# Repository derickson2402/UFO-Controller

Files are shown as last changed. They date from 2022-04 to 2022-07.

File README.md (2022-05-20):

# UFO-Controller

This summer, several of us wanted to build some quadcopter drones (what can I say, we're a house full of bored engineers :smiley:).
Eventually, we'd like to hook up FPV cameras, GPS units, and some other fun gizmos so that we can do cool stuff like FPV racing, autonomous path following with GPS, and smart object detection and wayfinding using computer vision.
Currently the project is in early stages, but I am documenting all the software as I go and when we have everything working I will make sure to include assembly instructions as well.

Much of the transmitter code is extended from [akarsh98](https://github.com/akarsh98) on GitHub and [this guide on PPM via Arduino](https://quadmeup.com/generate-ppm-signal-with-arduino/). Thanks akarsh and Pawel!

## Included Files

Some of the code used here is from projects from almost a decade ago, so I made sure to grab a copy of all the libraries and such that are used here.
Each folder contains some component of either testing/building the drone, and each comes with its own README and any dependencies.

Folder | Description
---|---|
```Arduino-ISP```     | Copied from Arduino IDE built-in example 11. Allows an Uno to program a Nano over ISP
```Wiring-Diagrams``` | PCB designs and board pinouts for transceiver, flight controller, etc for KiCad 6.0. Includes KiCad files for MPU breakout board.
```Hardware-Tests```  | Various programs for verifying that individual electronic components are working
```MultiWii```        | Flight control software from [MultiWii.com](http://www.multiwii.com/)
```MultiWii-GUI```    | Configuration GUI for ```MultiWii```
```Transceiver```     | Instructions for using pair of Arduino as radio transmitter to drone

## Testing/Verifying Hardware

In the ```Hardware-Tests``` folder are some basic programs for testing that various components are working.
There is another README in the folder which will walk you through everything.
I highly recommend you verify all of your hardware is working correctly BEFORE trying everything together, since there is nothing worse than spending hours on a "software" bug that doesn't actually exist.
Plus if you're like me you bought the cheapest stuff you could find and there's a good chance it won't all work right :smiley:.

## Configuring VS Code IDE

If you are like me, you really hate the default Arduino IDE and you would rather use VS Code.
To do this:

1. Install the Arduino VS Code extension
2. Choose AVR programmer and Arduino Nano board
3. In ```c_cpp_properties.json```, update ```compilerPath```, ```includePath```, and ```forcedInclude``` so your machine's section matches that of the Arduino (basically tell intellisense to use the Arduino's compiler)
4. Add ```USBCON``` to ```defines``` in ```c_cpp_properties.json```
5. If you need 3rd-party libraries, put them in ```src``` in the root of this repo and symlink ```src``` in your code root folder to it (Arduino compiler should recognize the ```src``` folder automatically)

## Resources

- https://create.arduino.cc/projecthub/akarsh98/diy-arduino-based-quadcopter-drone-948153
- https://www.hackster.io/robocircuits/arduino-quadcopter-e618c6
- https://howtomechatronics.com/projects/diy-arduino-rc-transmitter/
- https://www.modelflight.com.au/blog/a-guide-to-understanding-lipo-batteries
- https://www.instructables.com/DJi-F450-Quadcopter-How-to-Build-Home-Built/
- http://www.rctutor.org/the-parts-list.html
- [Read-only Amazon link for parts](https://www.amazon.com/hz/wishlist/ls/1BKLT1DHMK0VX?ref_=wl_share)
- [PPM communication via Arduino](https://quadmeup.com/generate-ppm-signal-with-arduino/)

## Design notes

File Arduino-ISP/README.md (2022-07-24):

# Arduino-ISP

This submodule is for using an Arduino Uno to program another Arduino via the ISP port.
This is useful for instance if the usb port is blocked on a device, but it is most useful if you need to burn a bootloader to a new board.

You can find the online instructions for the example built into the Arduino IDE on [Arduino's website](https://docs.arduino.cc/built-in-examples/arduino-isp/ArduinoISP).
Below is a transcript of the instructions.

## 1. Upload The ISP Sketch To The Programmer

Before wiring anything, upload the ```Arduino-ISP.ino``` sketch to your programmer board.
This file is the same as the one in the Arduino IDE examples.
Make sure to use the Port and Model of the programmer board for this step.

## 2. Connect The Programmer To The Target Board

See the diagram below that matches your use case. You should use an Uno board as the programmer, but you can program any kind of board.
For boards other than Nano or Uno, see the official instructions so you don't brick your board.

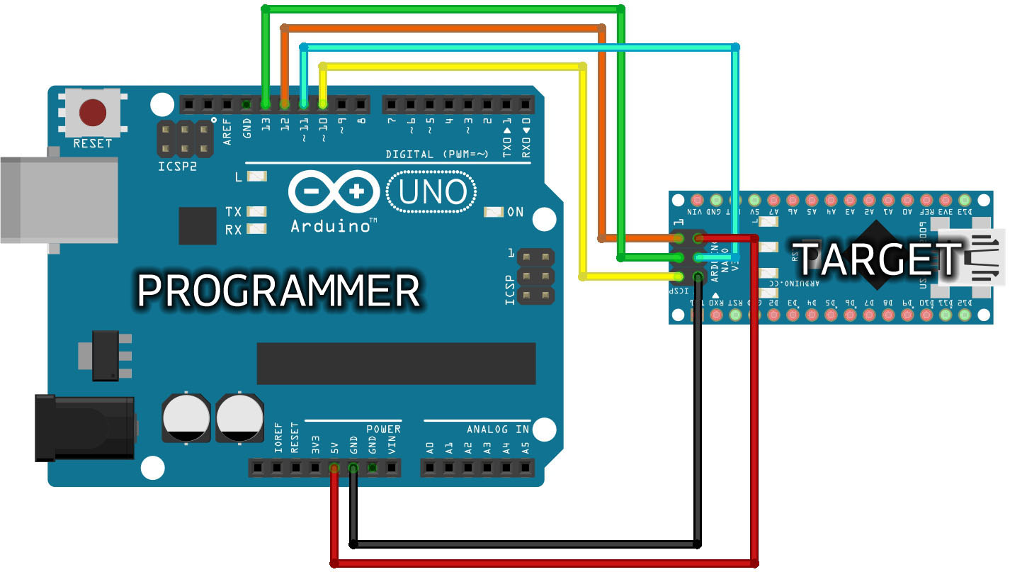
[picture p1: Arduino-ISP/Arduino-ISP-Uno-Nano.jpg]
Uno to Nano

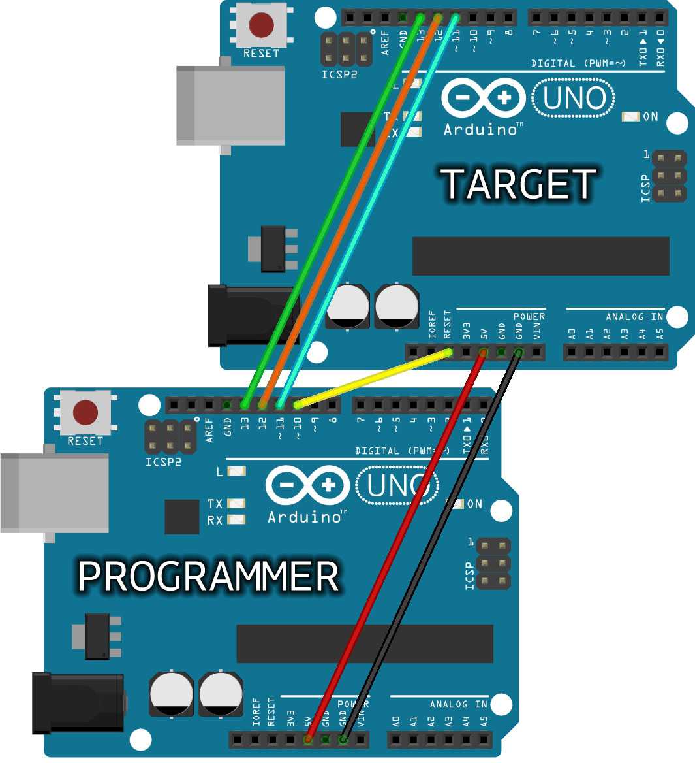
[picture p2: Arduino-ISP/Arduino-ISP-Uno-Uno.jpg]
Uno to Uno


## 3. Upload Code Or Bootloader

Once connected, you can upload to the target board as if it were connected directly to your computer.
Set the programmer to ```Arduino as ISP``` and the port and board type to the target board.
You can also choose ```Burn bootloader```, which may be necessary with new or mis-configured boards.

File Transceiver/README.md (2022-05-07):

# UFO Transceiver System

This submodule uses a pair of nRF24L01 transmitters, one as a transmitter one as a receiver. Check out the [RF24 GitHub](https://github.com/nRF24/RF24) for more help.
The PPM code is adapted from [this guide](https://quadmeup.com/generate-ppm-signal-with-arduino/) (thanks Pawel!).

## Wiring

See the corresponding images in ```Wiring-Diagrams``` for help wiring the modules.
It may be helpful to note that the chip needs a 3.3V power source but the logic pins are 5V tolerant, and therefore can be connected directly to the Arduino.
Also, to reduce noise, you might need a 10µF electrolytic or tantalum capacitor across the VCC and GND pins (this helps when using a poor power supply).
See the [COMMON_ISSUES.md](https://github.com/nRF24/RF24/blob/master/COMMON_ISSUES.md) file in the RF24 source repo for more help.

### Specific Configuration for Chips With External Antennas

nRF24L01+PA+LNA chips have a built in Power Amplifier and Low Noise Amplifier so they are very good for long range transmission.
With that said, they need an external 3.3V power source because said amplifier needs 3x as much current as the Arduino can give it.
Additionally, the chips may need electromagnetic shielding from the power supply.
Again see the [COMMON_ISSUES.md](https://github.com/nRF24/RF24/blob/master/COMMON_ISSUES.md) file in the RF24 source repo for more help.

## Deploying Code

When uploading the sketch to your Arduino's, there are some parameters at the top of ```Transceiver.ino``` you must configure.
There are short descriptions in the code but you can get more detail here:

1. Is the unit a receiver or a transmitter? Should debug mode be used?  
    a. Turning on debug mode deactivates PPM output (due to it needing timer interrupts)
2. Choose a unique 40 bit address for the Arduinos to talk on  
    a. Must be same for transmitter/receiver pair, and unique from other pairs
3. Choose a channel to use [0-125]  
    a. Must be same for transmitter/receiver pair, and unique from other pairs  
    b. Frequency band is 2,400MHz + (channel)MHz (so channel 81 = 2481MHz)  
    c. Higher channels sometimes interfere less with WiFi networks, may work better
4. You can re-define the CE and CSN pins in the code if you need (see nRF24 docs for more)
5. For the receiver only, choose PPM pin number and frame/pulse length  
    a. This must connect to the MultiWii controller pin 2  
    b. Communication is 12 channel PPM sum, where each channel is from [1000, 2000]µs (see [this guide](https://quadmeup.com/generate-ppm-signal-with-arduino/) for PPM help)  
    c. Channel order is set in MultiWii, default for this repo is in ```MultiWii/config.h``` as ```THROTTLE,YAW,PITCH,ROLL,AUX1,AUX2,AUX3,AUX4,8,9,10,11```  
    d. Frame length (total length of one transmission) is approximately ```(numChannels * 2000µsMaxSignalLength) + 3000µsFrameSpace```, and pulse length (signaling start of next channel) can be somewhere in [100, 500]µs

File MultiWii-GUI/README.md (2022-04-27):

# MultiWii Configuration GUI

This is a copy of the experimental GUI configuration program for MultiWii flight controllers.
You will need to install [Processing](https://processing.org/) on your computer, and then install the library ```controlp5``` by going into Processing under ```Sketch >> Import Library >> Add Library``` and searching for it (you can find help on their [GitHub](https://github.com/sojamo/controlp5) page).
When finished, you may need to restart Processing before launching ```MultiWiiConf.pde```.
See [MultiWii.com](http://www.multiwii.com/software) for help using the GUI.

---

Below is the original README from [multiwii/multiwii-gui-processing](https://github.com/multiwii/multiwii-gui-processing) on GitHub.

# multiwii-gui-processing for Processing 3.3 and later and ControlP5 2.2.5
# ***WORK IN PROGRESS***

Multiwii is a very common and respected flight controller, trully father of many version as CleanFligth, BetaFligth, iNAv and others.
But our beloved GUI was very outdated, this fork aims to fix that.

Currently working with:

Hardware: Arduino Mega, MPU6050, HMC5883L and BMP180.
Software: Processing 3.3 and ControlP5 release 2.2.5

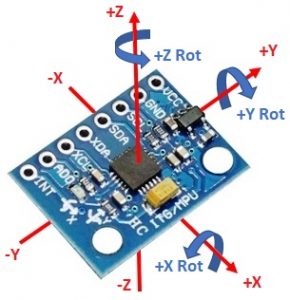
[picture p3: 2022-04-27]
Diagrams/Pinouts/MPU-6050-Orientation.jpg

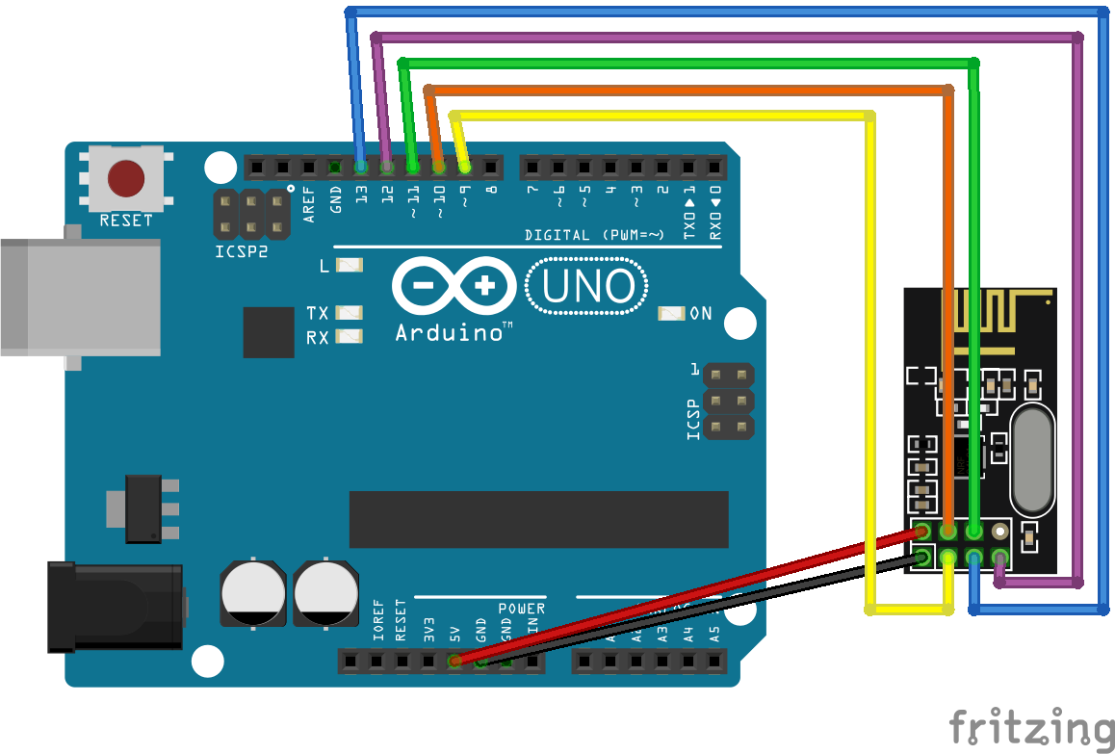
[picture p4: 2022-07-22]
Diagrams/Pinouts/UNO-nRF24L01.png

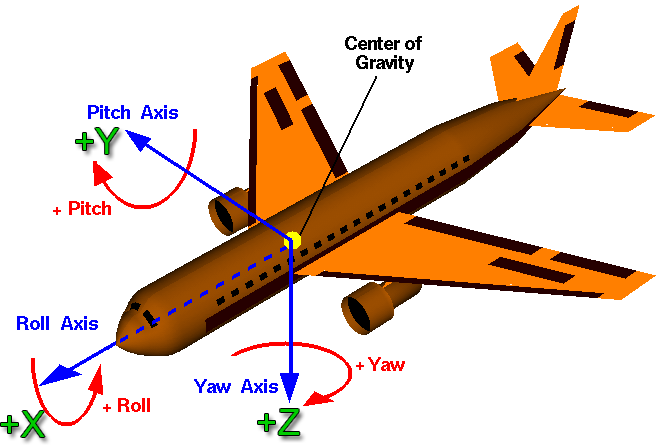
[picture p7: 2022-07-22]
Diagrams/NED Axes.png

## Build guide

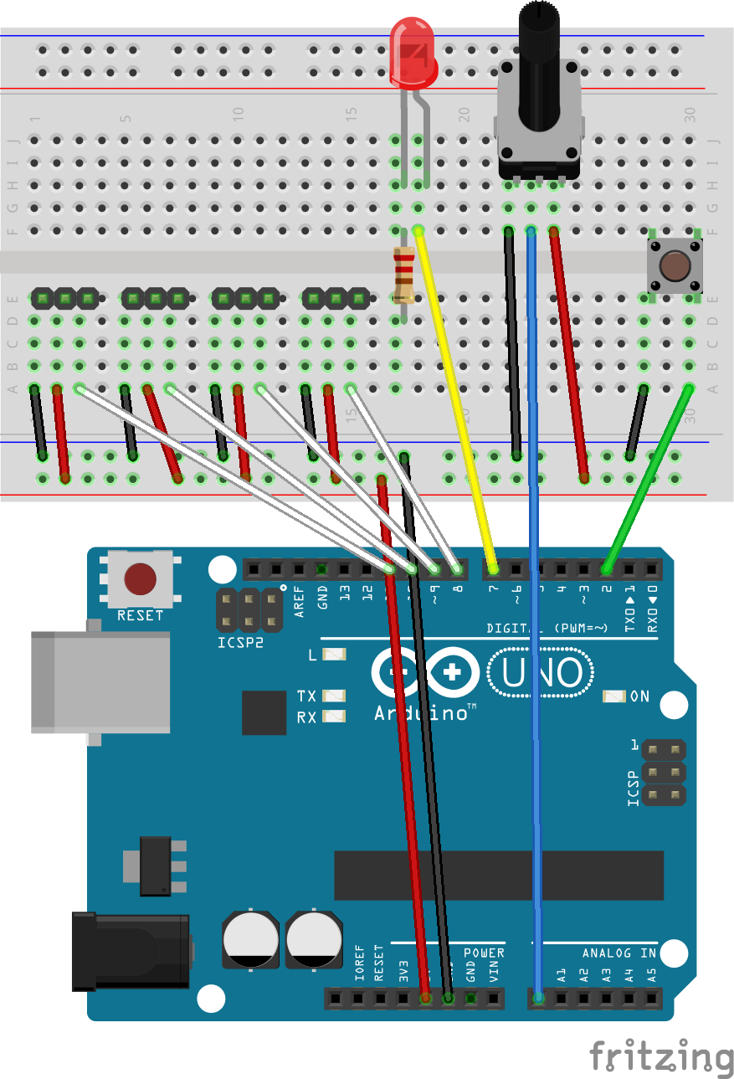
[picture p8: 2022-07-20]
Hardware-Tests/Motors/Motors Wiring Diagram.png

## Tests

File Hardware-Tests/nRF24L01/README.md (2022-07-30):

# Hardware-Tests/nRF24L01

The ```Transceiver``` program has a built-in debug mode which can be used for testing. Follow the instructions below to use this mode to verify that your transmitter and receiver are working correctly.

## 1. Test The Transmitter

Use the diagram in ```nRF24L01-TX-Test.png``` (embeded below) to create your transmitter.
Then deploy the Transceiver code with the ```DEBUG_MODE``` un-commented and the ```IS_RECEIVER``` commented.
This puts the board in transmitter debug mode.

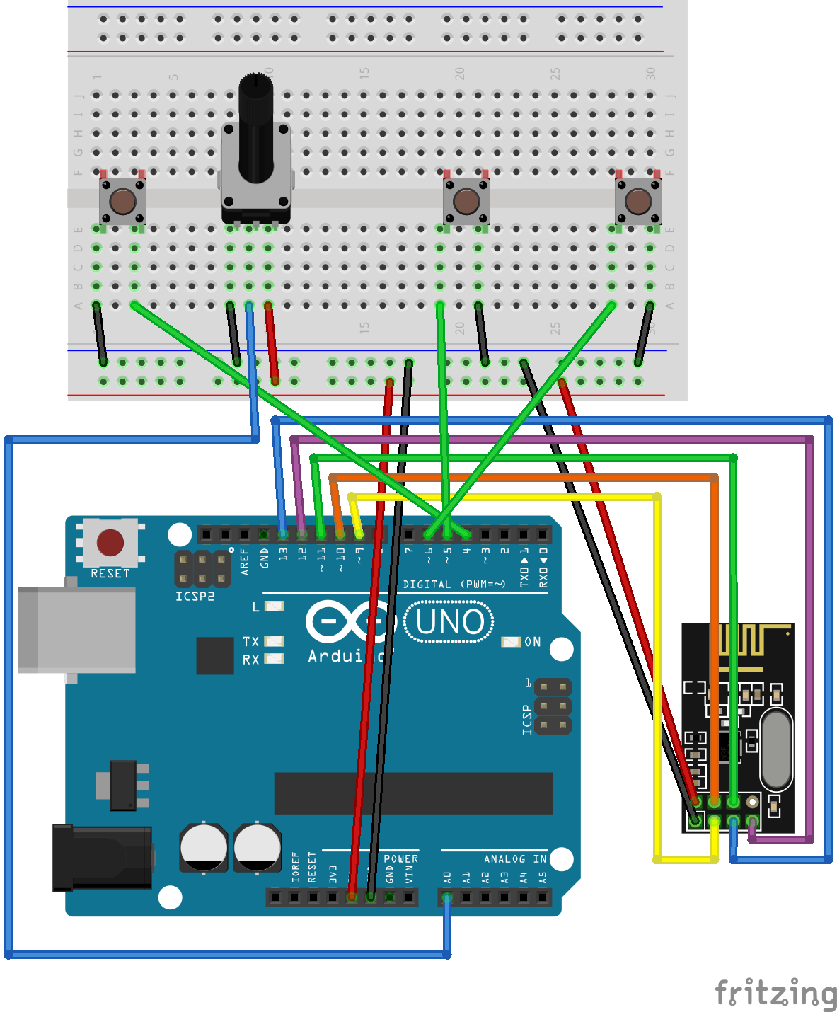
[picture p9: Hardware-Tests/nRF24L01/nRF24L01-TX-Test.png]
Wiring Diagram for testing transmission


You can connect via USB to verify that the data is being sent correctly.
Upon boot the radio will print its debug information.
Each second after that a copy of the data being transmitted is printed as ```throttle yaw pitch roll AUX1 AUX2```.
A working system should look like this after a few seconds:

```plaintext
SPI Frequency           = 10 Mhz
Channel                 = 120 (~ 2520 MHz)
Model                   = nRF24L01+
RF Data Rate            = 250 KBPS
RF Power Amplifier      = PA_MAX
RF Low Noise Amplifier  = Enabled
CRC Length              = 16 bits
Address Length          = 5 bytes
Static Payload Length   = 6 bytes
Auto Retry Delay        = 1500 microseconds
Auto Retry Attempts     = 15 maximum
Packets lost on
    current channel     = 0
Retry attempts made for
    last transmission   = 0
Multicast               = Disabled
Custom ACK Payload      = Disabled
Dynamic Payloads        = Disabled
Auto Acknowledgment     = Disabled
Primary Mode            = TX
TX address              = 0xe8e8f0f0e1
pipe 0 ( open ) bound   = 0xe8e8f0f0e1
pipe 1 (closed) bound   = 0xc2c2c2c2c2
pipe 2 (closed) bound   = 0xc3
pipe 3 (closed) bound   = 0xc4
pipe 4 (closed) bound   = 0xc5
pipe 5 (closed) bound   = 0xc6
0 127 127 127 0 0
0 127 127 127 0 0
0 127 127 127 0 0
78 152 102 127 0 0
78 152 102 127 0 0
78 152 102 127 0 0
78 127 127 127 0 0
```

## 2. Test the Receiver

Use the diagram in ```nRF24L01-RX-Test.png``` (embeded below) to create the receiver.
Deploy the Transceiver code with ```DEBUG_MODE``` and ```IS_RECEIVER``` un-commented.
This puts the board in receiver debug mode.

NOTE: See #12 in GitHub, there is some sort of hardware bug with using a Arduino Nano with the nRF24 chip.
Code is working correctly; if you do this setup with an UNO it will work.

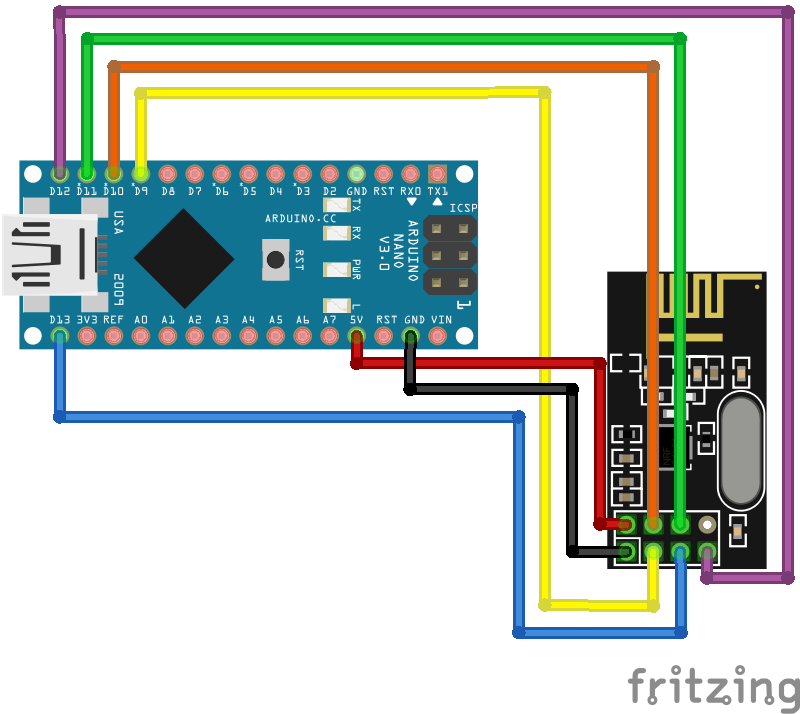
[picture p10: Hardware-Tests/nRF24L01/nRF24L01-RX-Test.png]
Wiring Diagram for testing receiving


Upload the transceiver code to the transmitter agin, but this time turn off debug mode.
Then plug the working transmitter into a wall outlet (not to your computer, as it is tedious to have multiple serial monitors open at once).
Connect the serial monitor to the receiver, and you should see the numbers from before on screen.
The radio information should also print, but it will be the receiver radio not the transmitter.
You should get something like this:

```plaintext
SPI Frequency           = 10 Mhz
Channel                 = 120 (~ 2476 MHz)
Model                   = nRF24L01+
RF Data Rate            = 250 KBPS
RF Power Amplifier      = PA_MAX
RF Low Noise Amplifier  = Enabled
CRC Length              = 16 bits
Address Length          = 5 bytes
Static Payload Length   = 6 bytes
Auto Retry Delay        = 1500 microseconds
Auto Retry Attempts     = 15 maximum
Packets lost on
    current channel     = 0
Retry attempts made for
    last transmission   = 0
Multicast               = Disabled
Custom ACK Payload      = Disabled
Dynamic Payloads        = Disabled
Auto Acknowledgment     = Disabled
Primary Mode            = RX
TX address              = 0xe7e7e7e7e7
pipe 0 (closed) bound   = 0xe7e7e7e7e7
pipe 1 ( open ) bound   = 0xe8e8f0f0e1
pipe 2 (closed) bound   = 0xc3
pipe 3 (closed) bound   = 0xc4
pipe 4 (closed) bound   = 0xc5
pipe 5 (closed) bound   = 0xc6
```

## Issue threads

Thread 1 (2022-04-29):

Create motion joystick for driving

derickson2402, 2022-04-29:
Originally I thought you could just plug an Xbox controller into an Arduino over USB and use its values to transmit to the drone. Turns out, there's only like 3 models of Arduino that have a full USB implementation available (normal ones aren't fast/powerful enough) so this won't work without a computer as a middle-man.

Instead, there are like 10 extra IMU chips lying around, so hooking one up to the transmitter and using it for motion controls should work just fine. Might be annoying later on (especially if there is drift) but it will be highly configurable and (hopefully) straightforward.

derickson2402, 2022-05-20:
Hm so forgot that the chip does not perform integration for us, it only reports change in angle and acceleration. Will need to perform the integration manually to track the current position of the 'joystick' and then send the corresponding values...

derickson2402, 2022-05-20:
Hmmm am I going to just have to write my own code to callibrate and track the sensor? This might be more difficult than just using an xbox controller :(

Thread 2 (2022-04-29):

Test transmitter/receiver pair

derickson2402, 2022-04-29:
The transmission code is already mostly implemented, but I haven't actually confirmed whether or not it works. See #1 as well.

derickson2402, 2022-05-08:
Note to self: this issue includes adding hardware tests for transmitter pair. Also, since it is hard to have 2 arduino serial streams on one computer, it might be best if the receiver had lights indicating the signal on an axis or button.

derickson2402, 2022-07-22:
Added test for the transmitter and receiver but it is not working and I cannot figure out why. It may be a power issue anyways. Going to bed for now

derickson2402, 2022-07-30:
Update, it's a bug with Arduino Nano. Code working in 8370c2d

Closed 2022-07-30.

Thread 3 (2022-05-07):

Transceiver: use 2 pointers for PPM data to not interfere with timers

derickson2402, 2022-05-07:
In Transceiver::UFOtoPPM, the actual ppm array pointer needs to be updated in an atomic block because the PPM signal is sent using timer interrupts. Otherwise the data might not be fully updated, and this can create tons of problems.

Currently memcpy is the only operation in atomic block, but it copies a whole int array over. It would be much faster to have 2 array pointers, primary and secondary, and just juggle them around so only 2 cycles are used to 'copy' the data.

Closed 2022-05-20.

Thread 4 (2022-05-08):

Transmitter: Stopp PPM comm when transceiver signal lost, allow MultiWii to handle lost signal

derickson2402, 2022-05-08:
MultiWii has a built-in way to deal with lost signal from a transmitter (you can modify it in config.h, but basically it just gently lowers drone to the ground). However this only works when PPM signal to MultiWii is lost, meaning that currently it can never be lost because the receiver constantly broadcasts even when not receiving data.

The only current fix in place is that the receiver will send 'safe' packets (0 throttle, no turn) but of course this means the drone can drop out of the air if someone sneezes while holding the transmitter

Ideally, receiver needs to recognize that it looses signal and stop PPM signal to MultiWii temporarily, so MultiWii is aware of loss of comm. Possible implementation is temporarily disabling interrupts whenever the radio has not received data for more than ~10ms (or some threshold to deal with intermittent noise/hardware bugs with the radio). Then the MultiWii can deal with the signal loss in a much safer way (ideally without destroying itself 🤞 )

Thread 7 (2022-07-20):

Test motors and ESC's

derickson2402, 2022-07-20:
As an engineer I want to test my motors and Electronic Speed Controllers. This lets me check that the hardware is not faulty, the wiring is secure, and that the power distribution to the motors is working.

Closed 2022-07-21.

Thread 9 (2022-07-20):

Test battery monitoring

derickson2402, 2022-07-20:

derickson2402, 2022-08-17:
Bought some adapters for connecting the battery voltage pins to the board. Each cell is a max of like 4.1 volts so it should just be a matter of finding the pinout and plugging straight into the pins defined in MultiWii for battery monitoring

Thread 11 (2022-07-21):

Create simple Left Right Forward controller for testing

derickson2402, 2022-07-21:
Would like a simple controller with 3 buttons and a potentiometer for basic testing of the transmitter

derickson2402, 2022-07-22:
[70aad15](https://github.com/derickson2402/UFO-Controller/commit/70aad15698fd8f19c98a743bc9a95100079d95d6) adds a basic controller but is untested

derickson2402, 2022-07-22:
This is tested and works, and a diagram is included in ```Hardware-Tests/nRF24L01``` for reference. Note that transmission is still not working.

Closed 2022-07-22.

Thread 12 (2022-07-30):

Figure out how to use nRF24 with Arduino Nano

derickson2402, 2022-07-30:

derickson2402, 2022-11-15:
Realizing that I never tested a nano after getting everything working. Would be good to check. Also the nRF is using 3.3V, not sure if the logic is 3 or 5 though... and not sure what the nano is expecting

derickson2402, 2023-02-05:
https://forum.arduino.cc/t/nrf24lo1-with-arduino-nano-not-working/664139/6

Triple check the pin connections on the nano, they might be wrong

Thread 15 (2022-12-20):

Feature - On-board flight control PCB

derickson2402, 2022-12-20:
Drone will have 2 arduinos, 4 3-pin connectors for motor controllers, a radio, and a gyroscope.
```Diagrams/UFO-PCB``` contains the PCB for everything.

- [ ] Fork PCB to use UNO instead of NANO for radio
- [ ] Update PCB to run on externally regulated 5V with internal 3.3V stepdown
- [ ]

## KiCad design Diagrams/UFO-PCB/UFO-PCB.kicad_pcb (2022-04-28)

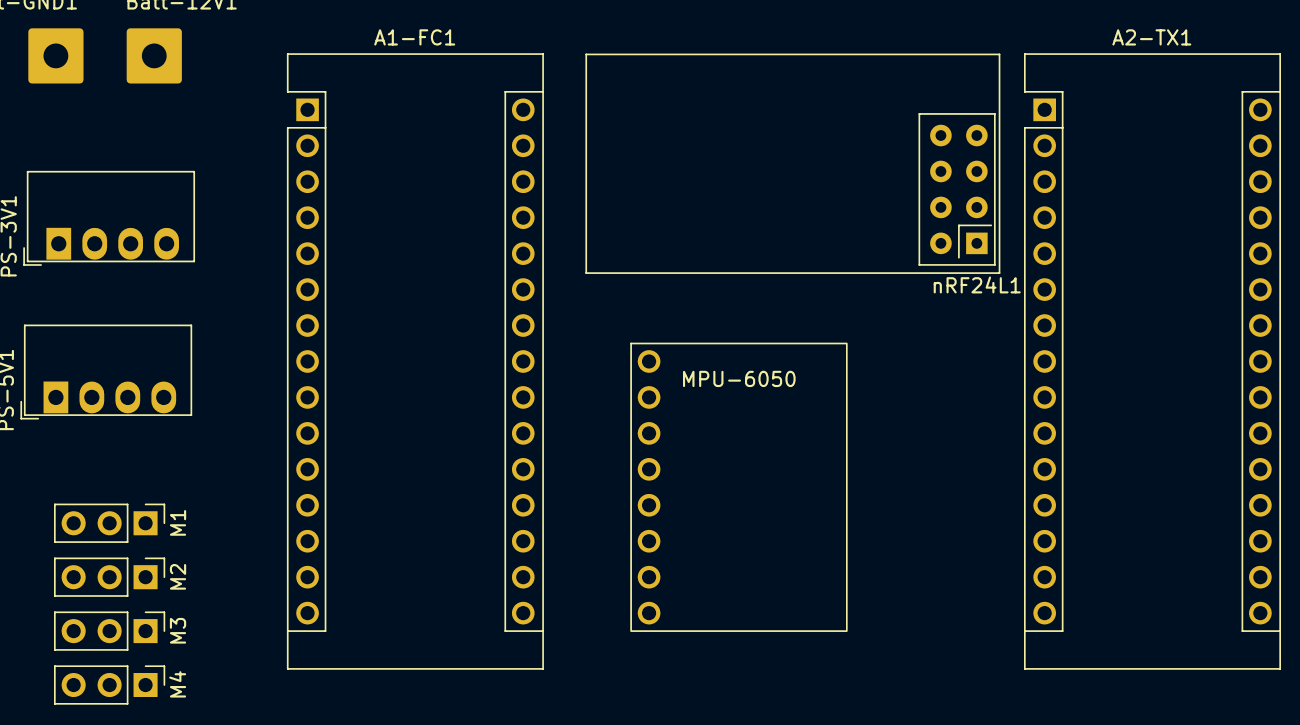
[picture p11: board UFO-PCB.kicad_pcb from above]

Board: 2 copper layers, 12 parts (0 on the bottom side), 16 nets, no tracks yet.

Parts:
A1-FC1, A2-TX1: Arduino_Nano_v3.x; Arduino_Nano
Batt-12V1: Conn_01x01_Male; SolderWire-1sqmm_1x01_D1.4mm_OD3.9mm
Batt-GND1: Conn_01x01_Male; SolderWire-1sqmm_1x01_D1.4mm_OD3.9mm
M1, M2, M3, M4: Motor_Servo; PinHeader_1x03_P2.54mm_Vertical
MPU-6050: MPU-6050-Breakout
PS-3V1, PS-5V1: MEE1S0305SC; Converter_DCDC_Murata_MEE1SxxxxSC_THT
nRF24L1: NRF24L01_Breakout; nRF24L01_Breakout

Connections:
+BATT: Batt-12V1.1, PS-3V1.2 (+Vin), PS-5V1.2 (+Vin)
GND: Batt-GND1.1, PS-3V1.1 (-Vin), PS-5V1.1 (-Vin)
unnamed: A1-FC1.4 (GND), A1-FC1.30 (VIN), A2-TX1.4 (GND), A2-TX1.30 (VIN), M1.2 (+), M1.3 (-), M2.2 (+), M2.3 (-), M3.2 (+), M3.3 (-), M4.2 (+), M4.3 (-), MPU-6050.1 (VCC), MPU-6050.2 (GND), PS-3V1.3 (-Vout), PS-5V1.3 (-Vout), PS-5V1.4 (+Vout), nRF24L1.1 (GND)
unnamed: A1-FC1.5 (D2), A2-TX1.6 (D3)
unnamed: A1-FC1.9 (D6), M1.1 (PWM)
unnamed: A1-FC1.10 (D7), M2.1 (PWM)
unnamed: A1-FC1.11 (D8), M3.1 (PWM)
unnamed: A1-FC1.12 (D9), M4.1 (PWM)
unnamed: A1-FC1.23 (A4), MPU-6050.4 (SDA)
unnamed: A1-FC1.24 (A5), MPU-6050.3 (SCL)
unnamed: A2-TX1.12 (D9), nRF24L1.4 (~CSN)
unnamed: A2-TX1.13 (D10), nRF24L1.3 (CE)
unnamed: A2-TX1.14 (D11), nRF24L1.6 (MOSI)
unnamed: A2-TX1.15 (D12), nRF24L1.7 (MISO)
unnamed: A2-TX1.16 (D13), nRF24L1.5 (SCK)
unnamed: PS-3V1.4 (+Vout), nRF24L1.2 (VCC)

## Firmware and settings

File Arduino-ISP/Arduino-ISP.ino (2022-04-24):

// ArduinoISP
// Copyright (c) 2008-2011 Randall Bohn
// If you require a license, see
// http://www.opensource.org/licenses/bsd-license.php
//
// This sketch turns the Arduino into a AVRISP using the following Arduino pins:
//
// Pin 10 is used to reset the target microcontroller.
//
// By default, the hardware SPI pins MISO, MOSI and SCK are used to communicate
// with the target. On all Arduinos, these pins can be found
// on the ICSP/SPI header:
//
//               MISO °. . 5V (!) Avoid this pin on Due, Zero...
//               SCK   . . MOSI
//                     . . GND
//
// On some Arduinos (Uno,...), pins MOSI, MISO and SCK are the same pins as
// digital pin 11, 12 and 13, respectively. That is why many tutorials instruct
// you to hook up the target to these pins. If you find this wiring more
// practical, have a define USE_OLD_STYLE_WIRING. This will work even when not
// using an Uno. (On an Uno this is not needed).
//
// Alternatively you can use any other digital pin by configuring
// software ('BitBanged') SPI and having appropriate defines for PIN_MOSI,
// PIN_MISO and PIN_SCK.
//
// IMPORTANT: When using an Arduino that is not 5V tolerant (Due, Zero, ...) as
// the programmer, make sure to not expose any of the programmer's pins to 5V.
// A simple way to accomplish this is to power the complete system (programmer
// and target) at 3V3.
//
// Put an LED (with resistor) on the following pins:
// 9: Heartbeat   - shows the programmer is running
// 8: Error       - Lights up if something goes wrong (use red if that makes sense)
// 7: Programming - In communication with the slave
//

#include "Arduino.h"
#undef SERIAL


#define PROG_FLICKER true

// Configure SPI clock (in Hz).
// E.g. for an ATtiny @ 128 kHz: the datasheet states that both the high and low
// SPI clock pulse must be > 2 CPU cycles, so take 3 cycles i.e. divide target
// f_cpu by 6:
//     #define SPI_CLOCK            (128000/6)
//
// A clock slow enough for an ATtiny85 @ 1 MHz, is a reasonable default:

#define SPI_CLOCK     (1000000/6)


// Select hardware or software SPI, depending on SPI clock.
// Currently only for AVR, for other architectures (Due, Zero,...), hardware SPI
// is probably too fast anyway.

#if defined(ARDUINO_ARCH_AVR)

#if SPI_CLOCK > (F_CPU / 128)
#define USE_HARDWARE_SPI
#endif

#endif

// Configure which pins to use:

// The standard pin configuration.
#ifndef ARDUINO_HOODLOADER2

#define RESET     10 // Use pin 10 to reset the target rather than SS
#define LED_HB    9
#define LED_ERR   8
#define LED_PMODE 7

// Uncomment following line to use the old Uno style wiring
// (using pin 11, 12 and 13 instead of the SPI header) on Leonardo, Due...

// #define USE_OLD_STYLE_WIRING

#ifdef USE_OLD_STYLE_WIRING

#define PIN_MOSI  11
#define PIN_MISO  12
#define PIN_SCK   13

#endif

// HOODLOADER2 means running sketches on the ATmega16U2 serial converter chips
// on Uno or Mega boards. We must use pins that are broken out:
#else

#define RESET       4
#define LED_HB      7
#define LED_ERR     6
#define LED_PMODE   5

#endif

// By default, use hardware SPI pins:
#ifndef PIN_MOSI
#define PIN_MOSI  MOSI
#endif

#ifndef PIN_MISO
#define PIN_MISO  MISO
#endif

#ifndef PIN_SCK
#define PIN_SCK   SCK
#endif

// Force bitbanged SPI if not using the hardware SPI pins:
#if (PIN_MISO != MISO) ||  (PIN_MOSI != MOSI) || (PIN_SCK != SCK)
#undef USE_HARDWARE_SPI
#endif


// Configure the serial port to use.
//
// Prefer the USB virtual serial port (aka. native USB port), if the Arduino has one:
//   - it does not autoreset (except for the magic baud rate of 1200).
//   - it is more reliable because of USB handshaking.
//
// Leonardo and similar have an USB virtual serial port: 'Serial'.
// Due and Zero have an USB virtual serial port: 'SerialUSB'.
//
// On the Due and Zero, 'Serial' can be used too, provided you disable autoreset.
// To use 'Serial': #define SERIAL Serial

#ifdef SERIAL_PORT_USBVIRTUAL
#define SERIAL SERIAL_PORT_USBVIRTUAL
#else
#define SERIAL Serial
#endif


// Configure the baud rate:

#define BAUDRATE  19200
// #define BAUDRATE 115200
// #define BAUDRATE 1000000


#define HWVER 2
#define SWMAJ 1
#define SWMIN 18

// STK Definitions
#define STK_OK      0x10
#define STK_FAILED  0x11
#define STK_UNKNOWN 0x12
#define STK_INSYNC  0x14
#define STK_NOSYNC  0x15
#define CRC_EOP     0x20 //ok it is a space...

void pulse(int pin, int times);

#ifdef USE_HARDWARE_SPI
#include "SPI.h"
#else

#define SPI_MODE0 0x00

class SPISettings {
  public:
    // clock is in Hz
    SPISettings(uint32_t clock, uint8_t bitOrder, uint8_t dataMode) : clock(clock) {
      (void) bitOrder;
      (void) dataMode;
    };

  private:
    uint32_t clock;

    friend class BitBangedSPI;
};

class BitBangedSPI {
  public:
    void begin() {
      digitalWrite(PIN_SCK, LOW);
      digitalWrite(PIN_MOSI, LOW);
      pinMode(PIN_SCK, OUTPUT);
      pinMode(PIN_MOSI, OUTPUT);
      pinMode(PIN_MISO, INPUT);
    }

    void beginTransaction(SPISettings settings) {
      pulseWidth = (500000 + settings.clock - 1) / settings.clock;
      if (pulseWidth == 0)
        pulseWidth = 1;
    }

    void end() {}

    uint8_t transfer (uint8_t b) {
      for (unsigned int i = 0; i < 8; ++i) {
        digitalWrite(PIN_MOSI, (b & 0x80) ? HIGH : LOW);
        digitalWrite(PIN_SCK, HIGH);
        delayMicroseconds(pulseWidth);
        b = (b << 1) | digitalRead(PIN_MISO);
        digitalWrite(PIN_SCK, LOW); // slow pulse
        delayMicroseconds(pulseWidth);
      }
      return b;
    }

  private:
    unsigned long pulseWidth; // in microseconds
};

static BitBangedSPI SPI;

#endif

void setup() {
  SERIAL.begin(BAUDRATE);

  pinMode(LED_PMODE, OUTPUT);
  pulse(LED_PMODE, 2);
  pinMode(LED_ERR, OUTPUT);
  pulse(LED_ERR, 2);
  pinMode(LED_HB, OUTPUT);
  pulse(LED_HB, 2);

}

int error = 0;
int pmode = 0;
// address for reading and writing, set by 'U' command
unsigned int here;
uint8_t buff[256]; // global block storage

#define beget16(addr) (*addr * 256 + *(addr+1) )
typedef struct param {
  uint8_t devicecode;
  uint8_t revision;
  uint8_t progtype;
  uint8_t parmode;
  uint8_t polling;
  uint8_t selftimed;
  uint8_t lockbytes;
  uint8_t fusebytes;
  uint8_t flashpoll;
  uint16_t eeprompoll;
  uint16_t pagesize;
  uint16_t eepromsize;
  uint32_t flashsize;
}
parameter;

parameter param;

// this provides a heartbeat on pin 9, so you can tell the software is running.
uint8_t hbval = 128;
int8_t hbdelta = 8;
void heartbeat() {
  static unsigned long last_time = 0;
  unsigned long now = millis();
  if ((now - last_time) < 40)
    return;
  last_time = now;
  if (hbval > 192) hbdelta = -hbdelta;
  if (hbval < 32) hbdelta = -hbdelta;
  hbval += hbdelta;
  analogWrite(LED_HB, hbval);
}

static bool rst_active_high;

void reset_target(bool reset) {
  digitalWrite(RESET, ((reset && rst_active_high) || (!reset && !rst_active_high)) ? HIGH : LOW);
}

void loop(void) {
  // is pmode active?
  if (pmode) {
    digitalWrite(LED_PMODE, HIGH);
  } else {
    digitalWrite(LED_PMODE, LOW);
  }
  // is there an error?
  if (error) {
    digitalWrite(LED_ERR, HIGH);
  } else {
    digitalWrite(LED_ERR, LOW);
  }

  // light the heartbeat LED
  heartbeat();
  if (SERIAL.available()) {
    avrisp();
  }
}

uint8_t getch() {
  while (!SERIAL.available());
  return SERIAL.read();
}
void fill(int n) {
  for (int x = 0; x < n; x++) {
    buff[x] = getch();
  }
}

#define PTIME 30
void pulse(int pin, int times) {
  do {
    digitalWrite(pin, HIGH);
    delay(PTIME);
    digitalWrite(pin, LOW);
    delay(PTIME);
  } while (times--);
}

void prog_lamp(int state) {
  if (PROG_FLICKER) {
    digitalWrite(LED_PMODE, state);
  }
}

uint8_t spi_transaction(uint8_t a, uint8_t b, uint8_t c, uint8_t d) {
  SPI.transfer(a);
  SPI.transfer(b);
  SPI.transfer(c);
  return SPI.transfer(d);
}

void empty_reply() {
  if (CRC_EOP == getch()) {
    SERIAL.print((char)STK_INSYNC);
    SERIAL.print((char)STK_OK);
  } else {
    error++;
    SERIAL.print((char)STK_NOSYNC);
  }
}

void breply(uint8_t b) {
  if (CRC_EOP == getch()) {
    SERIAL.print((char)STK_INSYNC);
    SERIAL.print((char)b);
    SERIAL.print((char)STK_OK);
  } else {
    error++;
    SERIAL.print((char)STK_NOSYNC);
  }
}

void get_version(uint8_t c) {
  switch (c) {
    case 0x80:
      breply(HWVER);
      break;
    case 0x81:
      breply(SWMAJ);
      break;
    case 0x82:
      breply(SWMIN);
      break;
    case 0x93:
      breply('S'); // serial programmer
      break;
    default:
      breply(0);
  }
}

void set_parameters() {
  // call this after reading parameter packet into buff[]
  param.devicecode = buff[0];
  param.revision   = buff[1];
  param.progtype   = buff[2];
  param.parmode    = buff[3];
  param.polling    = buff[4];
  param.selftimed  = buff[5];
  param.lockbytes  = buff[6];
  param.fusebytes  = buff[7];
  param.flashpoll  = buff[8];
  // ignore buff[9] (= buff[8])
  // following are 16 bits (big endian)
  param.eeprompoll = beget16(&buff[10]);
  param.pagesize   = beget16(&buff[12]);
  param.eepromsize = beget16(&buff[14]);

  // 32 bits flashsize (big endian)
  param.flashsize = buff[16] * 0x01000000
                    + buff[17] * 0x00010000
                    + buff[18] * 0x00000100
                    + buff[19];

  // AVR devices have active low reset, AT89Sx are active high
  rst_active_high = (param.devicecode >= 0xe0);
}

void start_pmode() {

  // Reset target before driving PIN_SCK or PIN_MOSI

  // SPI.begin() will configure SS as output, so SPI master mode is selected.
  // We have defined RESET as pin 10, which for many Arduinos is not the SS pin.
  // So we have to configure RESET as output here,
  // (reset_target() first sets the correct level)
  reset_target(true);
  pinMode(RESET, OUTPUT);
  SPI.begin();
  SPI.beginTransaction(SPISettings(SPI_CLOCK, MSBFIRST, SPI_MODE0));

  // See AVR datasheets, chapter "SERIAL_PRG Programming Algorithm":

  // Pulse RESET after PIN_SCK is low:
  digitalWrite(PIN_SCK, LOW);
  delay(20); // discharge PIN_SCK, value arbitrarily chosen
  reset_target(false);
  // Pulse must be minimum 2 target CPU clock cycles so 100 usec is ok for CPU
  // speeds above 20 KHz
  delayMicroseconds(100);
  reset_target(true);

  // Send the enable programming command:
  delay(50); // datasheet: must be > 20 msec
  spi_transaction(0xAC, 0x53, 0x00, 0x00);
  pmode = 1;
}

void end_pmode() {
  SPI.end();
  // We're about to take the target out of reset so configure SPI pins as input
  pinMode(PIN_MOSI, INPUT);
  pinMode(PIN_SCK, INPUT);
  reset_target(false);
  pinMode(RESET, INPUT);
  pmode = 0;
}

void universal() {
  uint8_t ch;

  fill(4);
  ch = spi_transaction(buff[0], buff[1], buff[2], buff[3]);
  breply(ch);
}

void flash(uint8_t hilo, unsigned int addr, uint8_t data) {
  spi_transaction(0x40 + 8 * hilo,
                  addr >> 8 & 0xFF,
                  addr & 0xFF,
                  data);
}
void commit(unsigned int addr) {
  if (PROG_FLICKER) {
    prog_lamp(LOW);
  }
  spi_transaction(0x4C, (addr >> 8) & 0xFF, addr & 0xFF, 0);
  if (PROG_FLICKER) {
    delay(PTIME);
    prog_lamp(HIGH);
  }
}

unsigned int current_page() {
  if (param.pagesize == 32) {
    return here & 0xFFFFFFF0;
  }
  if (param.pagesize == 64) {
    return here & 0xFFFFFFE0;
  }
  if (param.pagesize == 128) {
    return here & 0xFFFFFFC0;
  }
  if (param.pagesize == 256) {
    return here & 0xFFFFFF80;
  }
  return here;
}


void write_flash(int length) {
  fill(length);
  if (CRC_EOP == getch()) {
    SERIAL.print((char) STK_INSYNC);
    SERIAL.print((char) write_flash_pages(length));
  } else {
    error++;
    SERIAL.print((char) STK_NOSYNC);
  }
}

uint8_t write_flash_pages(int length) {
  int x = 0;
  unsigned int page = current_page();
  while (x < length) {
    if (page != current_page()) {
      commit(page);
      page = current_page();
    }
    flash(LOW, here, buff[x++]);
    flash(HIGH, here, buff[x++]);
    here++;
  }

  commit(page);

  return STK_OK;
}

#define EECHUNK (32)
uint8_t write_eeprom(unsigned int length) {
  // here is a word address, get the byte address
  unsigned int start = here * 2;
  unsigned int remaining = length;
  if (length > param.eepromsize) {
    error++;
    return STK_FAILED;
  }
  while (remaining > EECHUNK) {
    write_eeprom_chunk(start, EECHUNK);
    start += EECHUNK;
    remaining -= EECHUNK;
  }
  write_eeprom_chunk(start, remaining);
  return STK_OK;
}
// write (length) bytes, (start) is a byte address
uint8_t write_eeprom_chunk(unsigned int start, unsigned int length) {
  // this writes byte-by-byte, page writing may be faster (4 bytes at a time)
  fill(length);
  prog_lamp(LOW);
  for (unsigned int x = 0; x < length; x++) {
    unsigned int addr = start + x;
    spi_transaction(0xC0, (addr >> 8) & 0xFF, addr & 0xFF, buff[x]);
    delay(45);
  }
  prog_lamp(HIGH);
  return STK_OK;
}

void program_page() {
  char result = (char) STK_FAILED;
  unsigned int length = 256 * getch();
  length += getch();
  char memtype = getch();
  // flash memory @here, (length) bytes
  if (memtype == 'F') {
    write_flash(length);
    return;
  }
  if (memtype == 'E') {
    result = (char)write_eeprom(length);
    if (CRC_EOP == getch()) {
      SERIAL.print((char) STK_INSYNC);
      SERIAL.print(result);
    } else {
      error++;
      SERIAL.print((char) STK_NOSYNC);
    }
    return;
  }
  SERIAL.print((char)STK_FAILED);
  return;
}

uint8_t flash_read(uint8_t hilo, unsigned int addr) {
  return spi_transaction(0x20 + hilo * 8,
                         (addr >> 8) & 0xFF,
                         addr & 0xFF,
                         0);
}

char flash_read_page(int length) {
  for (int x = 0; x < length; x += 2) {
    uint8_t low = flash_read(LOW, here);
    SERIAL.print((char) low);
    uint8_t high = flash_read(HIGH, here);
    SERIAL.print((char) high);
    here++;
  }
  return STK_OK;
}

char eeprom_read_page(int length) {
  // here again we have a word address
  int start = here * 2;
  for (int x = 0; x < length; x++) {
    int addr = start + x;
    uint8_t ee = spi_transaction(0xA0, (addr >> 8) & 0xFF, addr & 0xFF, 0xFF);
    SERIAL.print((char) ee);
  }
  return STK_OK;
}

void read_page() {
  char result = (char)STK_FAILED;
  int length = 256 * getch();
  length += getch();
  char memtype = getch();
  if (CRC_EOP != getch()) {
    error++;
    SERIAL.print((char) STK_NOSYNC);
    return;
  }
  SERIAL.print((char) STK_INSYNC);
  if (memtype == 'F') result = flash_read_page(length);
  if (memtype == 'E') result = eeprom_read_page(length);
  SERIAL.print(result);
}

void read_signature() {
  if (CRC_EOP != getch()) {
    error++;
    SERIAL.print((char) STK_NOSYNC);
    return;
  }
  SERIAL.print((char) STK_INSYNC);
  uint8_t high = spi_transaction(0x30, 0x00, 0x00, 0x00);
  SERIAL.print((char) high);
  uint8_t middle = spi_transaction(0x30, 0x00, 0x01, 0x00);
  SERIAL.print((char) middle);
  uint8_t low = spi_transaction(0x30, 0x00, 0x02, 0x00);
  SERIAL.print((char) low);
  SERIAL.print((char) STK_OK);
}
//////////////////////////////////////////
//////////////////////////////////////////


////////////////////////////////////
////////////////////////////////////
void avrisp() {
  uint8_t ch = getch();
  switch (ch) {
    case '0': // signon
      error = 0;
      empty_reply();
      break;
    case '1':
      if (getch() == CRC_EOP) {
        SERIAL.print((char) STK_INSYNC);
        SERIAL.print("AVR ISP");
        SERIAL.print((char) STK_OK);
      }
      else {
        error++;
        SERIAL.print((char) STK_NOSYNC);
      }
      break;
    case 'A':
      get_version(getch());
      break;
    case 'B':
      fill(20);
      set_parameters();
      empty_reply();
      break;
    case 'E': // extended parameters - ignore for now
      fill(5);
      empty_reply();
      break;
    case 'P':
      if (!pmode)
        start_pmode();
      empty_reply();
      break;
    case 'U': // set address (word)
      here = getch();
      here += 256 * getch();
      empty_reply();
      break;

    case 0x60: //STK_PROG_FLASH
      getch(); // low addr
      getch(); // high addr
      empty_reply();
      break;
    case 0x61: //STK_PROG_DATA
      getch(); // data
      empty_reply();
      break;

    case 0x64: //STK_PROG_PAGE
      program_page();
      break;

    case 0x74: //STK_READ_PAGE 't'
      read_page();
      break;

    case 'V': //0x56
      universal();
      break;
    case 'Q': //0x51
      error = 0;
      end_pmode();
      empty_reply();
      break;

    case 0x75: //STK_READ_SIGN 'u'
      read_signature();
      break;

    // expecting a command, not CRC_EOP
    // this is how we can get back in sync
    case CRC_EOP:
      error++;
      SERIAL.print((char) STK_NOSYNC);
      break;

    // anything else we will return STK_UNKNOWN
    default:
      error++;
      if (CRC_EOP == getch())
        SERIAL.print((char)STK_UNKNOWN);
      else
        SERIAL.print((char)STK_NOSYNC);
  }
}

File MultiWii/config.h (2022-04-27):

#ifndef CONFIG_H_
#define CONFIG_H_

/*************************************************************************************************/
/****           CONFIGURABLE PARAMETERS                                                       ****/
/*************************************************************************************************/

/* this file consists of several sections
 * to create a working combination you must at least make your choices in section 1.
 * 1 - BASIC SETUP - you must select an option in every block.
 *      this assumes you have 4 channels connected to your board with standard ESCs and servos.
 * 2 - COPTER TYPE SPECIFIC OPTIONS - you likely want to check for options for your copter type
 * 3 - RC SYSTEM SETUP
 * 4 - ALTERNATE CPUs & BOARDS - if you have
 * 5 - ALTERNATE SETUP - select alternate RX (SBUS, PPM, etc.), alternate ESC-range, etc. here
 * 6 - OPTIONAL FEATURES - enable nice to have features here (FlightModes, LCD, telemetry, battery monitor etc.)
 * 7 - TUNING & DEVELOPER - if you know what you are doing; you have been warned
 *     - (ESCs calibration, Dynamic Motor/Prop Balancing, Diagnostics,Memory savings.....)
 * 8 - DEPRECATED - these features will be removed in some future release
 */

/* Notes:
 * 1. parameters marked with (*) in the comment are stored in eeprom and can be changed via serial monitor or LCD.
 * 2. parameters marked with (**) in the comment are stored in eeprom and can be changed via the GUI
 */


/*************************************************************************************************/
/*****************                                                                 ***************/
/****************  SECTION  1 - BASIC SETUP                                                *******/
/*****************                                                                 ***************/
/*************************************************************************************************/

  /**************************    The type of multicopter    ****************************/
    //#define GIMBAL
    //#define BI
    //#define TRI
    //#define QUADP
#define QUADX
    //#define Y4
    //#define Y6
    //#define HEX6
    //#define HEX6X
    //#define HEX6H  // New Model
    //#define OCTOX8
    //#define OCTOFLATP
    //#define OCTOFLATX
    //#define FLYING_WING
    //#define VTAIL4
    //#define AIRPLANE
    //#define SINGLECOPTER
    //#define DUALCOPTER
    //#define HELI_120_CCPM
    //#define HELI_90_DEG

  /****************************    Motor minthrottle    *******************************/
    /* Set the minimum throttle command sent to the ESC (Electronic Speed Controller)
       This is the minimum value that allow motors to run at a idle speed  */
    //#define MINTHROTTLE 1300 // for Turnigy Plush ESCs 10A
    //#define MINTHROTTLE 1120 // for Super Simple ESCs 10A
    //#define MINTHROTTLE 1064 // special ESC (simonk)
    //#define MINTHROTTLE 1050 // for brushed ESCs like ladybird
    #define MINTHROTTLE 1150 // (*) (**)

  /****************************    Motor maxthrottle    *******************************/
    /* this is the maximum value for the ESCs at full power, this value can be increased up to 2000 */
    #define MAXTHROTTLE 1850

  /****************************    Mincommand          *******************************/
    /* this is the value for the ESCs when they are not armed
       in some cases, this value must be lowered down to 900 for some specific ESCs, otherwise they failed to initiate */
    #define MINCOMMAND  1000

  /**********************************  I2C speed for old WMP config (useless config for other sensors)  *************/
    #define I2C_SPEED 100000L     //100kHz normal mode, this value must be used for a genuine WMP
    //#define I2C_SPEED 400000L   //400kHz fast mode, it works only with some WMP clones

  /***************************    Internal i2c Pullups   ********************************/
    /* enable internal I2C pull ups (in most cases it is better to use external pullups) */
    //#define INTERNAL_I2C_PULLUPS

  /**********************************  constant loop time  ******************************/
    #define LOOP_TIME 2800

  /**************************************************************************************/
  /*****************          boards and sensor definitions            ******************/
  /**************************************************************************************/
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

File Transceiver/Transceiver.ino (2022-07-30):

/*##############################################################################

Date
	21 July 2022

Written By
	Dan Erickson (dan@danerick.com)

Description
	Radio transceiver for controlling UFO drone, adapted from akarsh98 and
	DzikuVx on GitHub. Before deploying, the parameters below must be defined
	according to your setup (you can likely use the defaults and just change
	IS_RECEIVER). Debugging output can be enabled, but you may want to take a
	look at the corresponding Hardware-Tests files when doing this.

	Please see the README in the 'Transceiver' folder for more.

Project URL
	https://github.com/derickson2402/UFO-Controller.git

##############################################################################*/

// You must set the following items before deploying. See README for help
// #define DEBUG_ON                      // Print debug output (turns off PPM)
#define IS_RECEIVER                      // Leave for RX, comment out for TX
#define PIPE_NUM         0xE8E8F0F0E1LL  // 40 bit 'Address' the radios use
#define CHANNEL_24G      120             // Channel 0-125 to use on 2.4GHz band
#define PIN_RADIO_CE     9               // Pin to radio CE
#define PIN_RADIO_CSN    10              // Pin to radio CSN

// Following values are receiver only, you can ignore for the transmitter
#define PIN_PPM          2               // Pin to use for PPM comm to MultiWii
#define PPM_FRAME_LEN    27000           // PPM Frame length of a packet in µs
#define PPM_PULSE_LEN    400             // PPM pulse length in µs

/*############################################################################*/

#include "Joystick.h"
#include <SPI.h>
#include <nRF24L01.h>
#include <RF24.h>
#include <util/atomic.h>
#if defined(DEBUG_ON)
	#include <printf.h>
#endif
#if !defined(IS_RECEIVER)
	#include "src/I2Cdev.h"
	#include "src/MPU6050.h"
	#include <Wire.h>
#endif


/* Translate 8-bit packet from Arduino to PPM array of [1000,2000]µs channels.
 * Updates PPM packet in memory so PPM pin will automatically send data to
 * MultiWii */
void UFOtoPPM(UFODataPacket& data, volatile int* ppm);


/* Configure serial communication to the Arduino running MultiWii controller.
 * Uses PPM over PIN_PPM */
void configPPM(volatile int* ppm);

/* Configure the radio for transmission. Settings must be the same for both
 * radios to communicate */
void configRadio(RF24& radio);

/*############################################################################*/

RF24 radio(PIN_RADIO_CE, PIN_RADIO_CSN); // Reference to nRF24 radio
UFODataPacket data;       // Datapacket sent Arduino -> Arduino over nRF24 radio
unsigned long lastComm;   // Time in ms of last packet received from transmitter
// Note we need lastComm since receiver will continue broadcasting PPM data to
// MultiWii forever, whether new packets are received or not, so MultiWii
// timeouts will not do anything. Therefore receiver handles timeouts.
// TODO: See #4
#if defined(IS_RECEIVER)
	volatile int ppm[12]; // Globally readable PPM packet to MultiWii
#else
	Joystick * joystick = new SimpleFLR(data);  // Joystick to pull values from
#endif

void setup() {
	#if defined(DEBUG_ON)
		Serial.begin(115200);
		while (!Serial) { /* Make sure serial comms are up */}
		printf_begin();
	#endif
	configRadio(radio);
	#if defined(IS_RECEIVER) && !defined(DEBUG_ON)
		configPPM(ppm);
	#elif !defined(IS_RECEIVER)
		Wire.begin();
	#endif
}

void loop() {
	#if defined(IS_RECEIVER)
		// Keep polling radio, timer interrupt will handle PPM to MultiWii
		while (radio.available()) {
			radio.read(&data,sizeof(UFODataPacket));
			// lastComm = millis();
		}
		#if !defined(DEBUG_ON)
			// Check if we possibly lost connection after ~1 second
			// TODO: See #4, we need a safer way to handle comm loss
			if (millis() - lastComm > 1000) {
				data.clear();
				UFOtoPPM(data, ppm);
			}
		#endif
	#else
		// Get joystick values and transmit them to receiver
		joystick->update();
		radio.stopListening();
		radio.write(&data, sizeof(UFODataPacket));
	#endif
	#if defined(DEBUG_ON)
		// Print out current data and slow down printing rate
		Serial.print(data.throttle, DEC); Serial.print(' ');
		Serial.print(data.yaw,      DEC); Serial.print(' ');
		Serial.print(data.pitch,    DEC); Serial.print(' ');
		Serial.print(data.roll,     DEC); Serial.print(' ');
		Serial.print(data.AUX1,     DEC); Serial.print(' ');
		Serial.println(data.AUX2,   DEC);
		delay(1000);
	#endif
}

/*############################################################################*/

void configRadio(RF24& radio) {
	if (!radio.begin()) {
		while (true) {
			Serial.println(F("radio hardware not responding"));
			delay(2000);
		}
	}
	// We don't want ACK since we are broadcasting packets quickly and won't
	// re-send them (think UDP on IP networks)
	radio.setAutoAck(false);
	radio.setDataRate(RF24_250KBPS);
	radio.setPayloadSize(sizeof(UFODataPacket));
	radio.setPALevel(RF24_PA_MAX);
	radio.setChannel(CHANNEL_24G);
	radio.setAddressWidth(5);

	// Receiver listens, transmitter talks. Also receiver will try to recognize
	// lost signal
	#if defined(IS_RECEIVER)
		radio.openReadingPipe(1, PIPE_NUM);
		radio.startListening();
		lastComm = millis();
	#else
		radio.openWritingPipe(PIPE_NUM);
		radio.stopListening();
	#endif
	#if defined(DEBUG_ON)
		// Run after Serial and radio are up to confirm mode
		radio.printPrettyDetails();
	#endif
}

void UFOtoPPM(UFODataPacket& data, volatile int* ppm) {
	// UFODataPacket uses 8-bit data but PPM needs pulses of duration in µs.
	// Store results to temp location in memory, moves ppm to point to it, then
	// copies over data. This means we block interrupts from as few CPU cycles
	// as possible when updating ppm, while ensuring we don't send bogus data.
	int ppmAux[6];     // Temporary data block for new PPM packet
	volatile int* ppmPtr = ppm; // Ptr back to original PPM packet
	ppmAux[0] = map(data.throttle, 0, 255, 1000, 2000);
	ppmAux[1] = map(data.yaw,      0, 255, 1000, 2000);
	ppmAux[2] = map(data.pitch,    0, 255, 1000, 2000);
	ppmAux[3] = map(data.roll,     0, 255, 1000, 2000);
	ppmAux[4] = map(data.AUX1,     0, 1,   1000, 2000);
	ppmAux[5] = map(data.AUX2,     0, 1,   1000, 2000);
	ATOMIC_BLOCK(ATOMIC_RESTORESTATE) {
		ppm = ppmAux; // Look at new memory while we copy over
	}
	// Copy over actual data
	for (uint8_t i = 0; i < 6; ++i) {
		ppm[i] = ppmAux[i];
	}
	ATOMIC_BLOCK(ATOMIC_RESTORESTATE) {
		ppm = ppmPtr; // All done, ppmAux will go out of scope now
	}
}
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

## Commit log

2022-04-24 Add copies of board pinouts, add README docs
2022-04-24 Add MultiWii files
    [config.h]
2022-04-27 Add MultiWii conf, add Transmitter/Receiver, update documentation
    [config.h]
2022-04-27 Add pinout diagrams, start main pcb design
    [UFO-PCB.kicad_pcb, UFO-PCB.kicad_sch]
2022-04-28 Update Controller PCB with all components, no traces yet
    [UFO-PCB.kicad_pcb, UFO-PCB.kicad_sch]
2022-05-20 Speed up data packet transfer, resolve #3
    [Transceiver.ino]
2022-07-20 Add motor and ESC hardware testing
    Added simple Arduino sketch to test and calibrate the Electronic Speed Controllers and the motors.
    Includes a Processing sketch with a simple slider for adjusting the speed of the controllers.
2022-07-20 Fix bugs in Motors tests, remove Processing GUI
    [Motors.ino]
2022-07-20 Update Motors test with better docs and wiring diagram
    [Motors.fzz]
2022-07-21 Simplify Motor hardware tests, update docs
    This closes Test motors and ESC's #7
2022-07-21 Rename Diagrams folder
    [UFO-PCB.kicad_pcb, UFO-PCB.kicad_sch]
2022-07-21 Fix source files and Sketch structure
    [UFO-PCB.kicad_sch]
2022-07-22 Create Joystick interface, fix Transceiver RX/TX macros
    [Joystick.h, Transceiver.ino]
2022-07-22 Add transceiver tests and diagrams
    See #2
    [nRF24L01-RX-Test.fzz, nRF24L01-TX-Test.fzz]
2022-07-24 Clarify instructions for Arduino ISP
2022-07-30 Tidy up debug mode in Transceiver code, document bug in #12
    [Transceiver.ino]
